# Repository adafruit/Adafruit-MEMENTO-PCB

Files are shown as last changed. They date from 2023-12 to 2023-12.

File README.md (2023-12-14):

## Adafruit MEMENTO - Python Programmable DIY Camera PCB

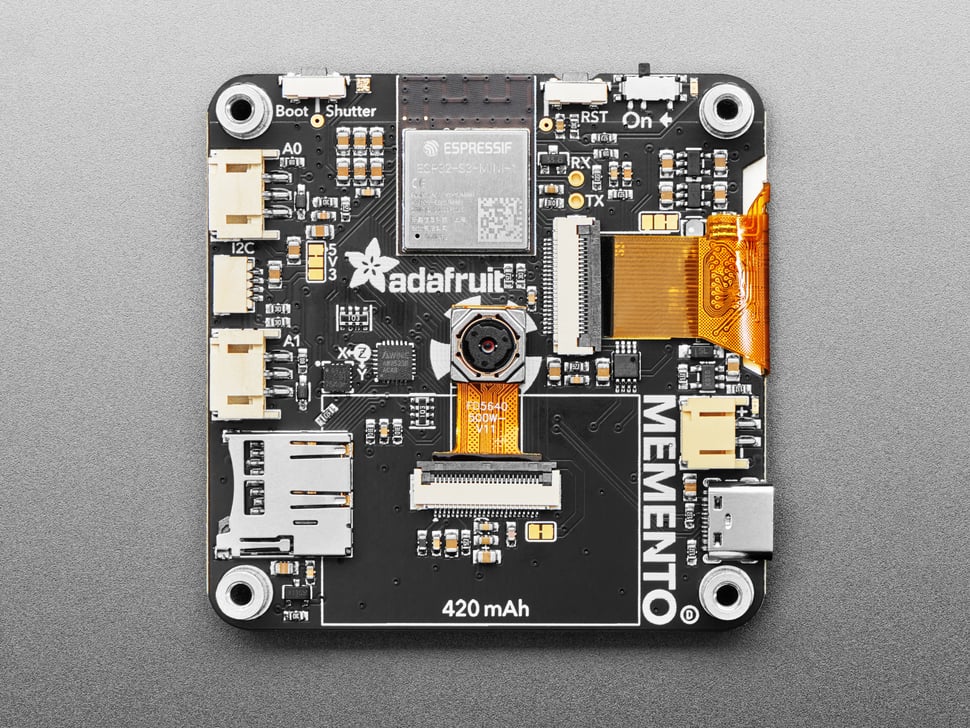
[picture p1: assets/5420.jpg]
<a href="http://www.adafruit.com/products/5420"><br/>
Click here to purchase one from the Adafruit shop</a>

PCB files for the Adafruit MEMENTO - Python Programmable DIY Camera. 

Format is EagleCAD schematic and board layout
* https://www.adafruit.com/product/5420

### Description

Make memories, or just a cool camera-based project, with Adafruit's MEMENTO Camera Board. It's a development board with everything you need to create programmable camera and vision projects: with a camera module, TFT preview screen, buttons, SD card slot and driven by a powerful ESP32-S3 with 2 MB of PSRAM for buffering 5 MegaPixel camera images.

This product is just the mainboard, and does not come with an enclosure, LED ring, hardware, SD card, or battery.

The ESP32-S3 is a WiFi and Bluetooth LE capable, 240 MHz dual core Tensilica processor - much like the famous ESP32. The S3 adds native USB support so it's great for use with Arduino or CircuitPython. The S3 also has the ability to interface with raw camera modules. The cameras require 12 GPIO pins and fast data transfer in order to get images off the sensor, and then a lot of memory for storing 2560 x 1920 images - which is why we picked an S3 module with 2MB of PSRAM so that we can read JPEGs into memory for saving onto an SD card.

To make the board easy to use we added a ton of supporting hardware, here's a full list of the hardware included:

* ESP32-S3 module with 8 MB Flash, 2 MB PSRAM - dual core 240MHz Tensilica with WiFi and BTLE.
* OV5640 camera module with 72 degree view and auto-focus motor - 5MP camera sensor with JPEG encoder built in.
* 1.54" 240x240 Color TFT - For previewing the camera images, or user interface design.
* MicroSD card slot - Store images or animations to any SPI-capable micro SD card.
* Two Digital/Analog Stemma Ports - JST PH-3 connectors for A0, A1 and power+ground for adding external buttons, LEDs, or sensors. Can provide 3V or 5V power.
* I2C Stemma QT Port - Connect just about any I2C sensor you please with a Stemma QT JST SH port, provides 3.3V power and logic.
* LIS3DH Accelerometer - Triple-access accelerometer can detect orientation, shaking or movement.
* LiPoly battery charging support - Use a 3.7/4.2V 350mA or 420mA battery for on-the-go snaps.
* 6 User Buttons - change modes, preview saved images, play DOOM (?). Connected through a GPIO expander
* Buzzer - play tones or alerts, or indicate when a photo was successfully taken
* Analog Microphone - Can be used as a sensor to detect loud sounds, not for recording video with audio.
* Shutter button - Connected to GPIO 0 for entering the ROM bootloader
* Reset button - For entering the bootloader or starting over
* On/Off switch - Cut all power when using a battery 
* USB Type C for programming the ESP32-S3, as well as REPL access in CircuitPython and charging the optional LiPoly battery
* Breakout pads for hardware UART - for more intense debugging needs, solder wires to the through-hole pads to connect to a console cable.
* Four M3 standoffs for mounting or enclosure attachment.

We've got both Arduino and CircuitPython example code that lets you preview the camera, adjust settings, and take photos that are saved to disk. However, we recommend CircuitPython because the compilation time in Arduino is pretty intense due to the huge amount of code required to run the camera. CircuitPython is fast to develop for and our library will make it easy to start making custom camera projects.

### License

Adafruit invests time and resources providing this open source design, please support Adafruit and open-source hardware by purchasing products from [Adafruit](https://www.adafruit.com)!

Designed by Limor Fried/Ladyada for Adafruit Industries.

Creative Commons Attribution/Share-Alike, all text above must be included in any redistribution. 
See license.txt for additional details.

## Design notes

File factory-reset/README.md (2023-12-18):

## Factory Reset file - MEMENTO - Python Programmable DIY Camera

This is the factory reset file for the MEMENTO - Python Programmable DIY Camera.

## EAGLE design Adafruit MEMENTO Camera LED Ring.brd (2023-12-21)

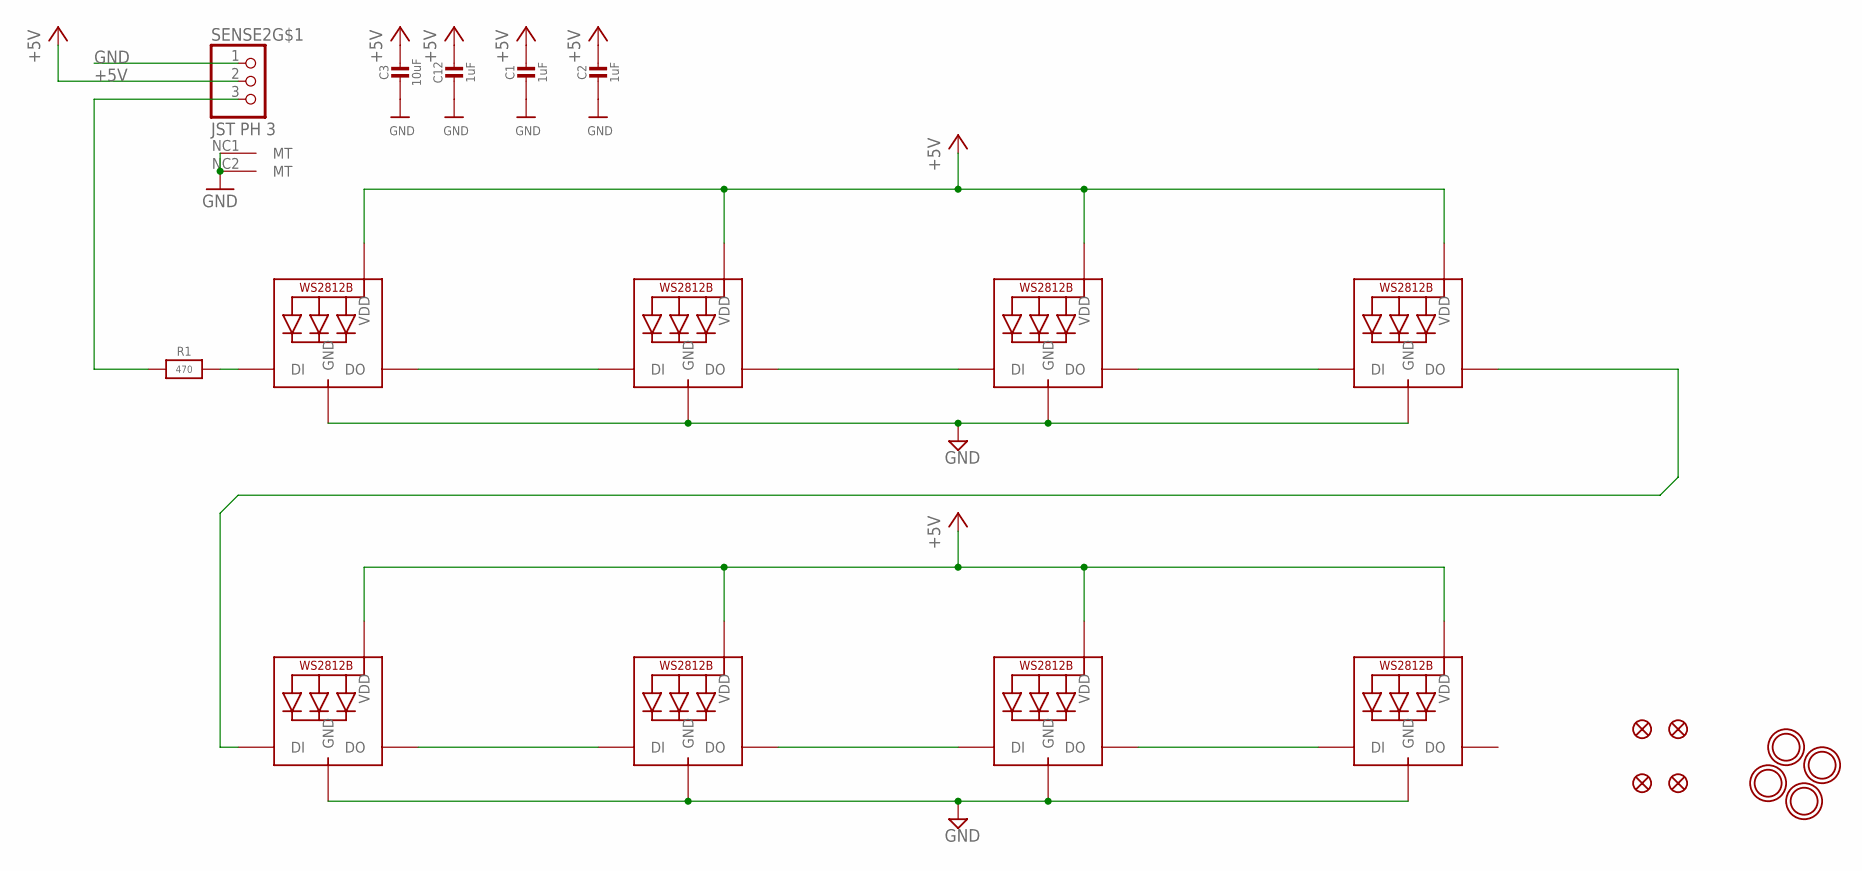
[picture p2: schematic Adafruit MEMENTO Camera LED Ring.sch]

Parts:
C1, C2, C12: 1uF; 0603-NO
C3: 10uF; 0805-NO
FID1, FID2, FID3, FID4: FIDUCIAL_1MM
LED1, LED3, LED5, LED7, LED9, LED11, LED13, LED15: WS2812B_5050N; WS2812B-NARROW
R1: 470; 0603-NO
SENSE2: JST PH 3; JSTPH3
U$1, U$2, U$3, U$4: MOUNTINGHOLE3.0THIN; MOUNTINGHOLE_3.0_PLATEDTHIN

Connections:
+5V: C1.1, C2.1, C3.1, C12.1, LED1.1-VDD (VDD), LED3.1-VDD (VDD), LED5.1-VDD (VDD), LED7.1-VDD (VDD), LED9.1-VDD (VDD), LED11.1-VDD (VDD), LED13.1-VDD (VDD), LED15.1-VDD (VDD), SENSE2.2
GND: C1.2, C2.2, C3.2, C12.2, LED1.3-GND (GND), LED3.3-GND (GND), LED5.3-GND (GND), LED7.3-GND (GND), LED9.3-GND (GND), LED11.3-GND (GND), LED13.3-GND (GND), LED15.3-GND (GND), SENSE2.1, SENSE2.NC1 (MT), SENSE2.NC2 (MT)
IN: R1.1, SENSE2.3
unnamed: LED1.2-DOUT (DO), LED3.4-DIN (DI)
unnamed: LED3.2-DOUT (DO), LED5.4-DIN (DI)
unnamed: LED5.2-DOUT (DO), LED7.4-DIN (DI)
unnamed: LED9.2-DOUT (DO), LED11.4-DIN (DI)
unnamed: LED11.2-DOUT (DO), LED13.4-DIN (DI)
unnamed: LED13.2-DOUT (DO), LED15.4-DIN (DI)
unnamed: LED7.2-DOUT (DO), LED9.4-DIN (DI)
unnamed: LED1.4-DIN (DI), R1.2

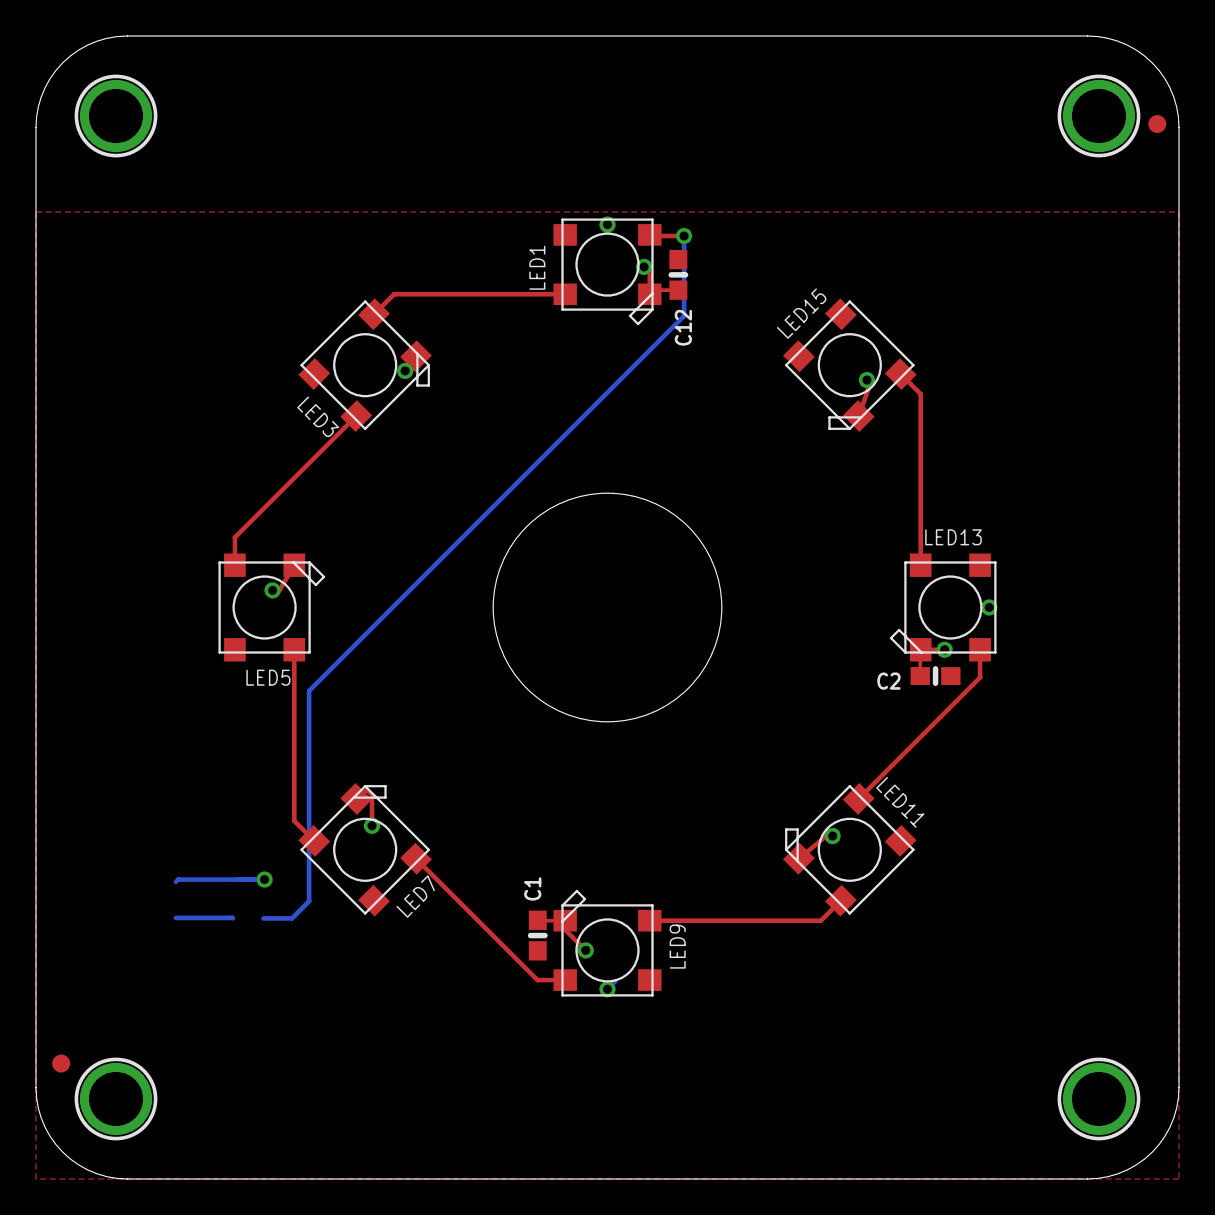
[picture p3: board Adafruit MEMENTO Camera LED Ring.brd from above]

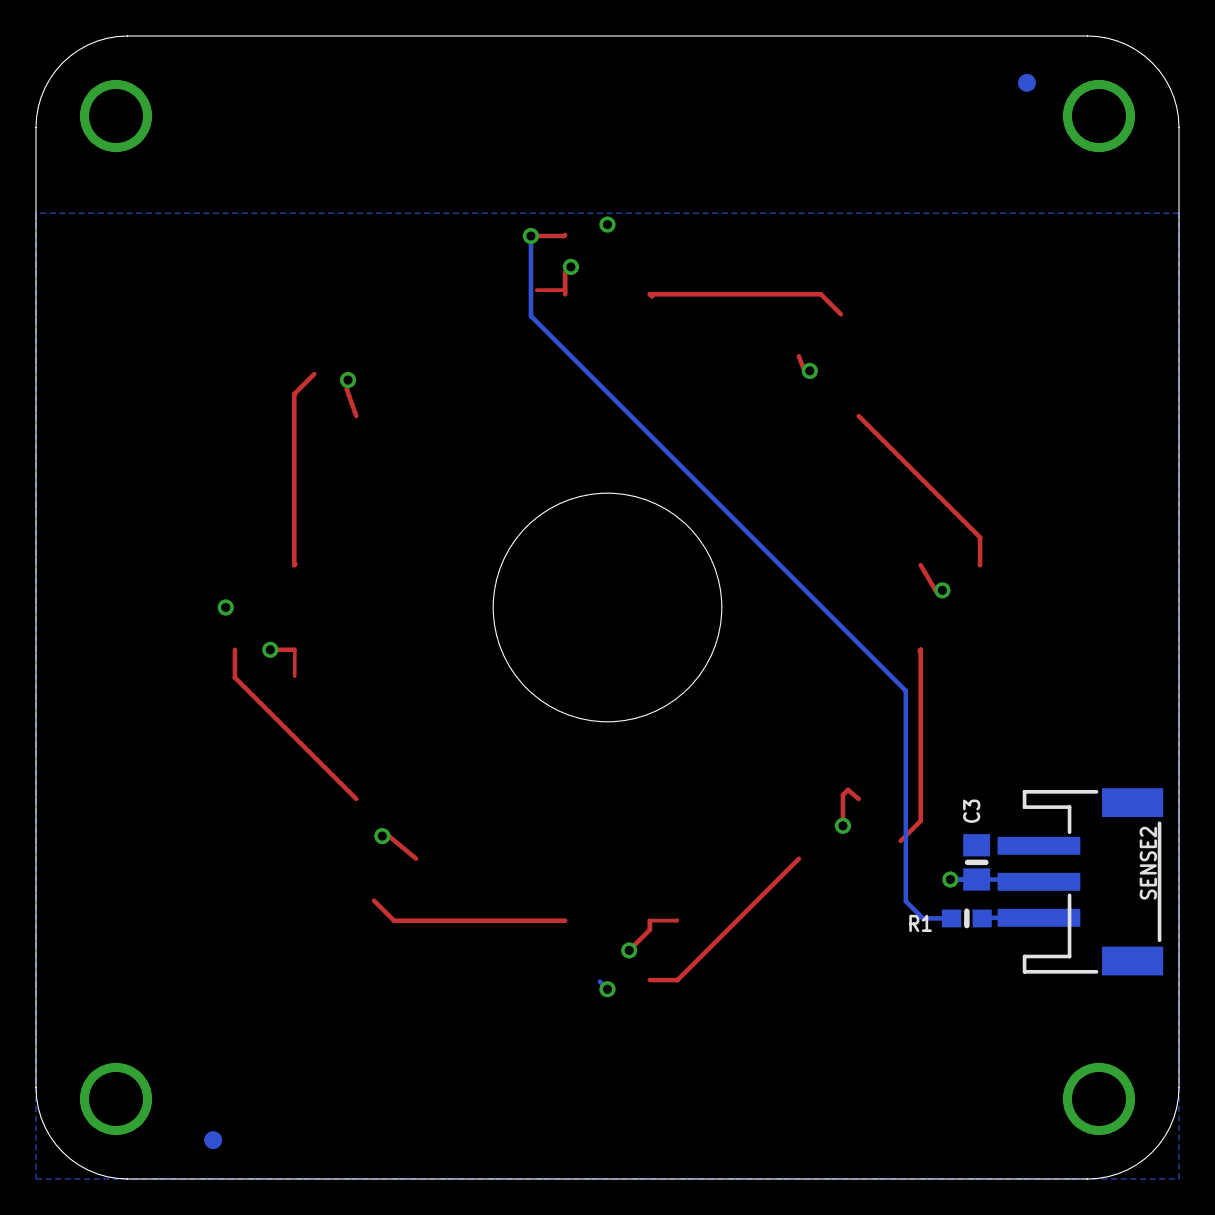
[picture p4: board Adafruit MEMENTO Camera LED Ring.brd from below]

Board: 2 copper layers, 63.5 x 63.5 mm, 24 parts (6 on the bottom side), 11 nets.

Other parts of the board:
U$8: MEMENTO_LED_BOT
U$9: MEMENTO_LED_TOP

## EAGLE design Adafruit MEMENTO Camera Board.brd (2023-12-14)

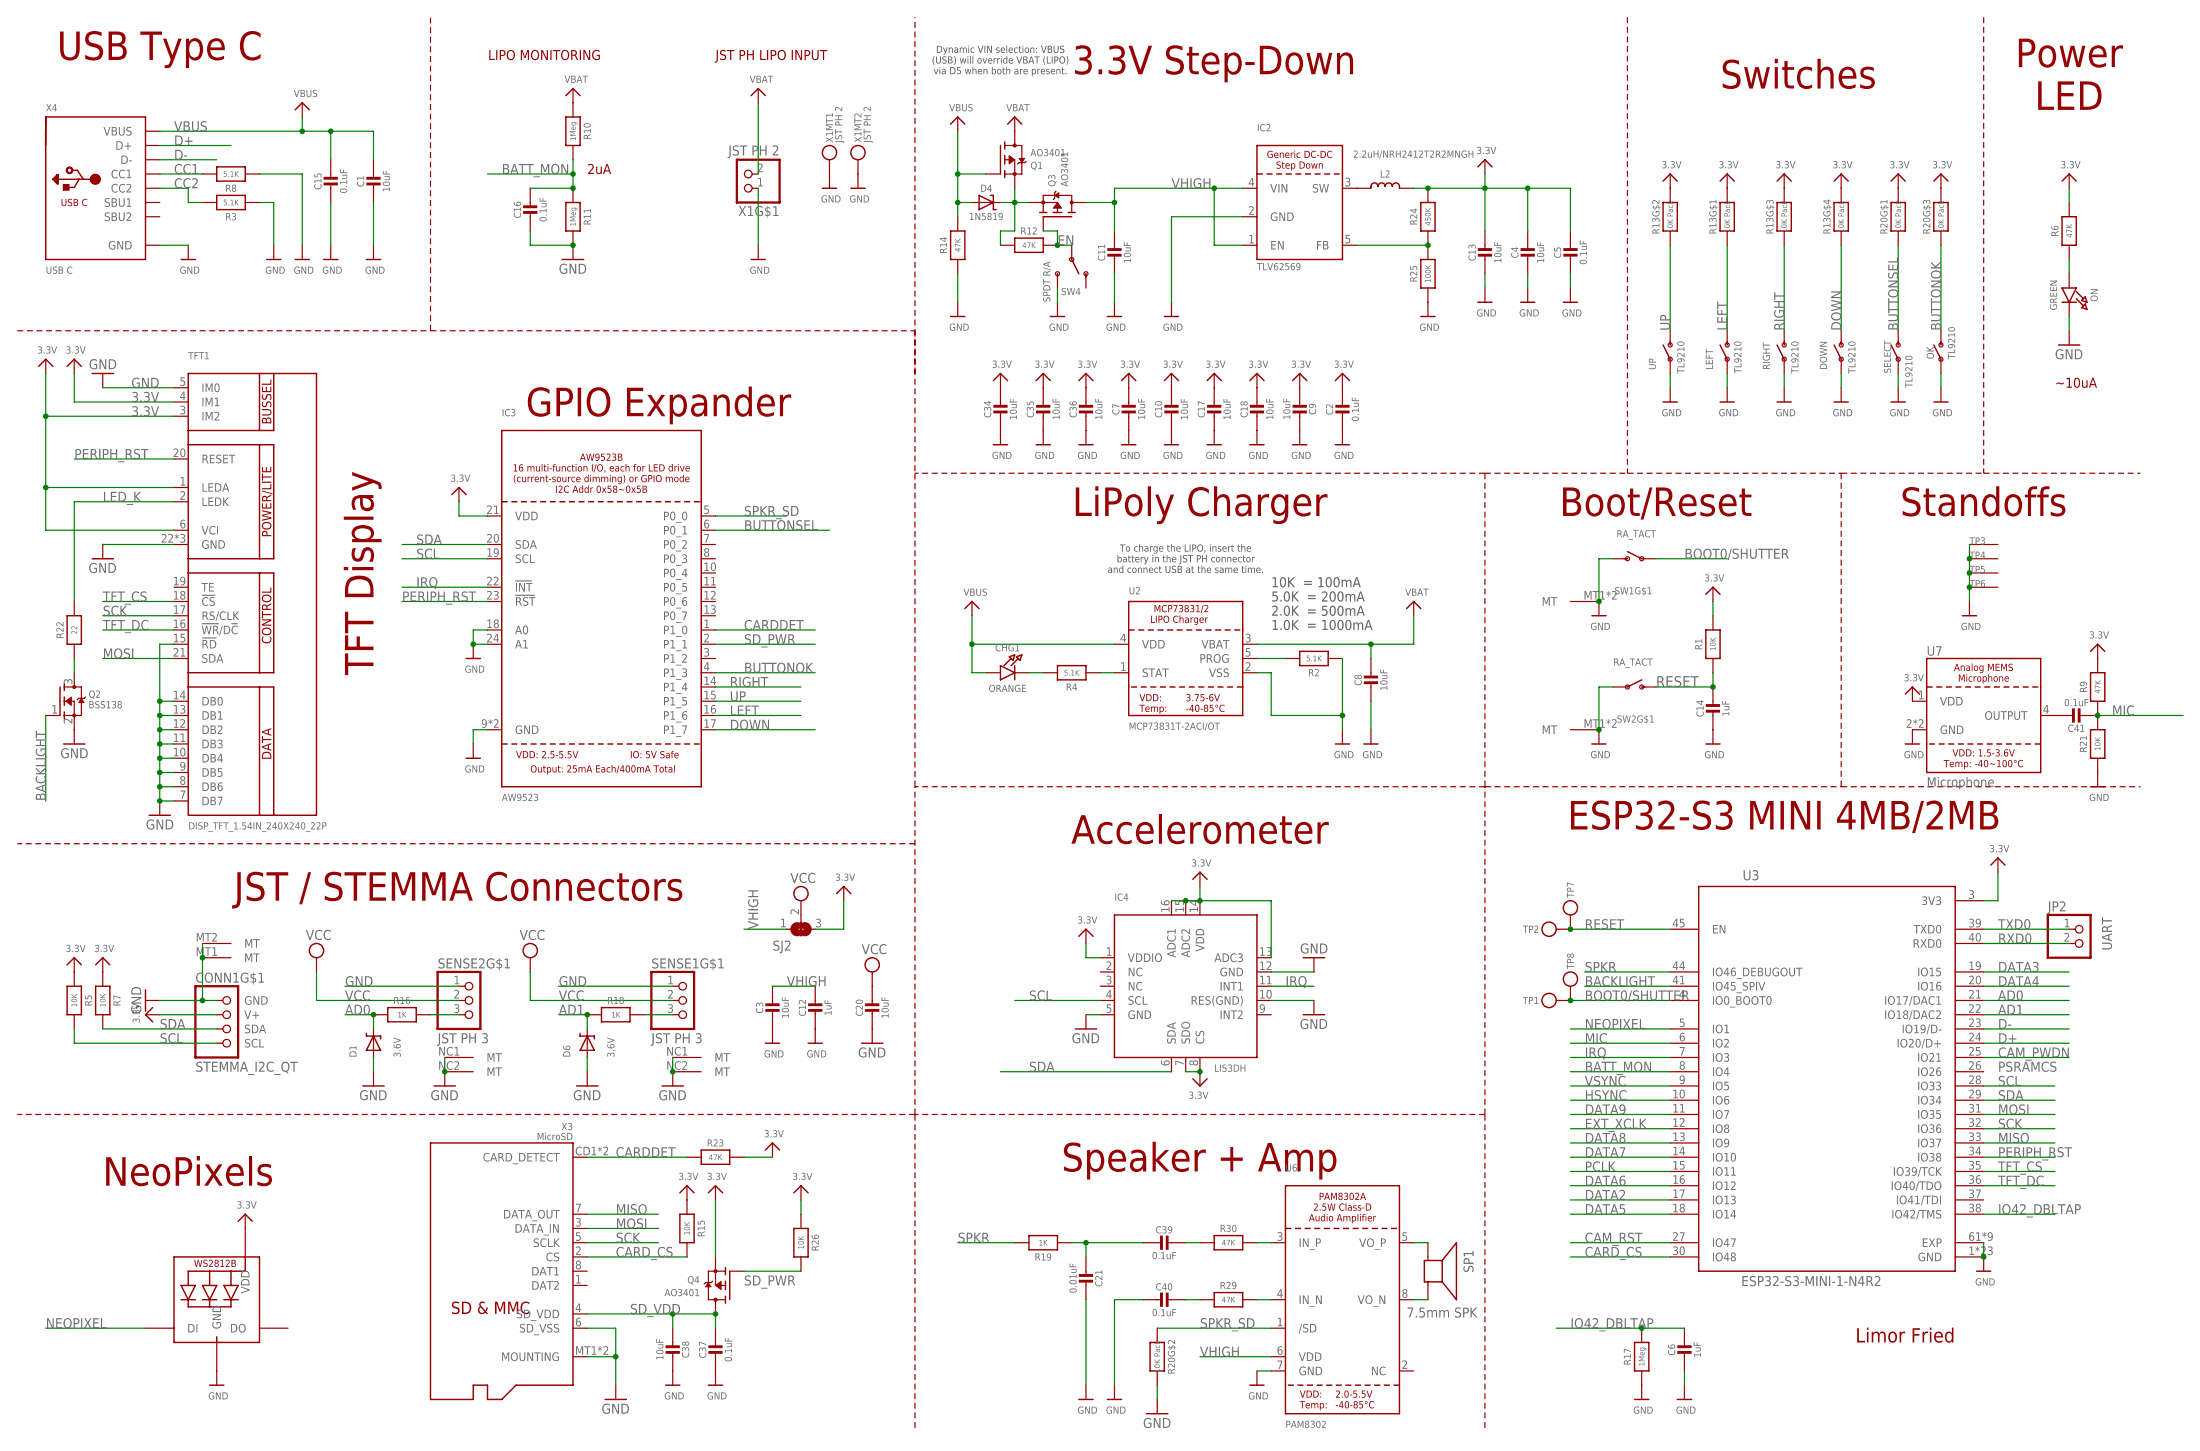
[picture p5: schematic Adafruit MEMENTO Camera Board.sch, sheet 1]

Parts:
C1, C3, C4, C7, C8, C9, C10, C11, C13, C17, C18, C20, C34, C35, C36, C38: 10uF; 0805-NO
C2, C5, C15, C16, C37, C39, C40, C41: 0.1uF; 0603-NO
C6, C12, C14: 1uF; 0603-NO
C21: 0.01uF; 0603-NO
CHG1: ORANGE; CHIPLED_0603_NOOUTLINE
CONN1: STEMMA_I2C_QT; JST_SH4
D1, D6: 3.6V; SOD-323
D4: 1N5819; SOD-123
DOWN: TL9210
IC2: TLV62569; SOT23-5
IC3: AW9523; QFN24_4MM_SMSC
IC4: LIS3DH; LGA16_3X3MM
JP2: UART; 1X02_ROUND
L2: 2.2uH/NRH2412T2R2MNGH; INDUCTOR_TAIYOYUDEN_NR3015
LED2: WS2812B_SK6805_1515; SK6805_1515
LEFT: TL9210
OK: TL9210
ON: GREEN; CHIPLED_0603_NOOUTLINE
Q1, Q3, Q4: AO3401; SOT23-R
Q2: BSS138; SOT23-WIDE
R1, R5, R7, R15, R21, R26: 10K; 0603-NO
R2, R3, R4, R8: 5.1K; 0603-NO
R6, R9, R12, R14, R23, R29, R30: 47K; 0603-NO
R10, R11, R17: 1Meg; 0603-NO
R13, R20: 10K Pack; RESPACK_4X0603
R16, R18, R19: 1K; 0603-NO
R22: 22; 0603-NO
R24: 450K; 0603-NO
R25: 100K; 0603-NO
RIGHT: TL9210
SELECT: TL9210
SENSE1, SENSE2: JST PH 3; JSTPH3
SJ2: SOLDERJUMPER_2WAY; SOLDERJUMPER_2WAY_OPEN_NOPASTE
SP1: 7.5mm SPK; BUZZER_SMT_7.5MM
SW1, SW2: RA_TACT; SPST_TACTILE_RA
SW4: SPDT R/A; SPDT_SMT_SSSS811101
TFT1: DISP_TFT_1.54IN_240X240_22P; TFT_1.54IN_240X240_22PIN
TP1, TP2, TP7, TP8: TESTPOINTROUND1.5MMNO; TESTPOINT_ROUND_1.5MM_NO
TP3, TP4, TP5, TP6: SEWTAP_SMTNUTM3; SMT_NUT_3MM
U2: MCP73831T-2ACI/OT; SOT23-5
U3: ESP32-S3-MINI-1-N4R2; ESP32-S2-MINI-1
U6: PAM8302; MSOP8_0.65MM
U7: Microphone; MEMS_MIC_2.75X1.85
UP: TL9210
X1: JST PH 2; JSTPH2_BATT
X3: MicroSD; MICROSD
X4: USB C; USB_C_CUSB31-CFM2AX-01-X

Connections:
3.3V: C2.1, C4.1, C5.1, C7.1, C9.2, C10.1, C13.1, C17.1, C18.1, C34.1, C35.1, C36.1, CONN1.2 (V+), IC3.21 (VDD), IC4.1 (VDDIO), IC4.7 (SDO), IC4.8 (CS), IC4.13 (ADC3), IC4.14 (VDD), IC4.15 (ADC2), IC4.16 (ADC1), L2.P$2 (2), LED2.2 (VDD), Q4.2 (S), R1.2, R5.1, R6.2, R7.1, R9.2, R13.5 (2), R13.6 (2), R13.7 (2), R13.8 (2), R15.2, R20.6 (2), R20.8 (2), R23.2, R24.2, R26.1, SJ2.3, TFT1.1 (LEDA), TFT1.3 (IM2), TFT1.4 (IM1), TFT1.6 (VCI), U3.3 (3V3), U7.1 (VDD); also elsewhere on the board
A1_JST1: R18.1, SENSE1.3
AD0: D1.C, R16.2, U3.21 (IO17/DAC1)
AD1: D6.C, R18.2, U3.22 (IO18/DAC2)
BACKLIGHT: Q2.1 (G), U3.41 (IO45_SPIV)
BATT_MON: C16.1, R10.2, R11.1, U3.8 (IO4)
BOOT0/SHUTTER: SW1.1, TP1.P$1, TP8.P$1, U3.4 (IO0_BOOT0)
BUTTONOK: IC3.4 (P1_3), OK.2 (S), R20.3 (1)
BUTTONSEL: IC3.6 (P0_1), R20.1, SELECT.2 (S)
CAM_PWDN: U3.25 (IO21); also elsewhere on the board
CAM_RST: U3.27 (IO47); also elsewhere on the board
CARDDET: IC3.1 (P1_0), R23.1, X3.CD1 (CARD_DETECT), X3.CD2 (CARD_DETECT)
CARD_CS: R15.1, U3.30 (IO48), X3.2 (CS)
CC1: R8.2, X4.A5 (CC1)
CC2: R3.2, X4.B5 (CC2)
D10_JST: R16.1, SENSE2.3
D+: U3.24 (IO20/D+), X4.A6 (D+), X4.B6 (D+)
D-: U3.23 (IO19/D-), X4.A7 (D-), X4.B7 (D-)
DATA2: U3.17 (IO13); also elsewhere on the board
DATA3: U3.19 (IO15); also elsewhere on the board
DATA4: U3.20 (IO16); also elsewhere on the board
DATA5: U3.18 (IO14); also elsewhere on the board
DATA6: U3.16 (IO12); also elsewhere on the board
DATA7: U3.14 (IO10); also elsewhere on the board
DATA8: U3.13 (IO9); also elsewhere on the board
DATA9: U3.11 (IO7); also elsewhere on the board
DOWN: DOWN.2 (S), IC3.17 (P1_7), R13.4 (1)
EN: Q3.1 (G), R12.2, SW4.B
EXT_XCLK: U3.12 (IO8); also elsewhere on the board
FB: IC2.5 (FB), R24.1, R25.2
GND: C1.2, C2.2, C3.2, C4.2, C5.2, C6.2, C7.2, C8.2, C9.1, C10.2, C11.2, C12.2, C13.2, C14.2, C15.2, C16.2, C17.2, C18.2, C20.2, C21.1, C34.2, C35.2, C36.2, C37.2, C38.1, C40.2, CONN1.1 (GND), CONN1.MT1 (MT), CONN1.MT2 (MT), D1.A, D6.A, DOWN.1, IC2.2 (GND), IC3.9 (GND), IC3.18 (A0), IC3.24 (A1), IC3.THERM (GND), IC4.5 (GND), IC4.10 (RES(GND)), IC4.12 (GND), LED2.4 (GND), LEFT.1, OK.1, ON.C, Q2.2 (S), R2.1, R3.1, R8.1, R11.2, R14.1, R17.1, R20.7 (2), R21.1, R25.1, RIGHT.1, SELECT.1, SENSE1.1, SENSE1.NC1 (MT), SENSE1.NC2 (MT), SENSE2.1, SENSE2.NC1 (MT), SENSE2.NC2 (MT), SW1.2 (S), SW1.MT1 (MT), SW1.MT2 (MT), SW2.1, SW2.MT1 (MT), SW2.MT2 (MT), SW4.C (S), TFT1.5 (IM0), TFT1.7 (DB7), TFT1.8 (DB6), TFT1.9 (DB5), TFT1.10 (DB4), TFT1.11 (DB3), TFT1.12 (DB2), TFT1.13 (DB1), TFT1.14 (DB0), TFT1.15 (!RD), TFT1.22 (GND), TFT1.SUPPORT1 (GND), TFT1.SUPPORT2 (GND), TP3.P$1, TP4.P$1, TP5.P$1, TP6.P$1, U2.2 (VSS), U3.1 (GND), U3.2 (GND), U3.42 (GND), U3.43 (GND), U3.46 (GND), U3.47 (GND), U3.48 (GND), U3.49 (GND), U3.50 (GND), U3.51 (GND), U3.52 (GND), U3.53 (GND), U3.54 (GND), U3.55 (GND), U3.56 (GND), U3.57 (GND), U3.58 (GND), U3.59 (GND), U3.60 (GND), U3.61 (EXP), U3.62 (GND), U3.63 (GND), U3.64 (GND), U3.65 (GND), U3.66 (EXP), U3.67 (EXP), U3.68 (EXP), U3.69 (EXP), U3.70 (EXP), U3.71 (EXP), U3.72 (EXP), U3.73 (EXP), U6.7 (GND), U7.2 (GND), U7.3 (GND), UP.1, X1.1, X1.NC1, X1.NC2, X3.6 (SD_VSS), X3.MT1 (MOUNTING), X3.MT2 (MOUNTING), X4.A1B12 (GND), X4.B1A12 (GND); also elsewhere on the board
HSYNC: U3.10 (IO6); also elsewhere on the board
IO42_DBLTAP: C6.1, R17.2, U3.38 (IO42/TMS)
IRQ: IC3.22 (!INT), IC4.11 (INT1), U3.7 (IO3)
LED_K: R22.1, TFT1.2 (LEDK)
LEFT: IC3.16 (P1_6), LEFT.2 (S), R13.1
MIC: C41.2, R9.1, R21.2, U3.6 (IO2)
MISO: U3.33 (IO37), X3.7 (DATA_OUT)
MOSI: TFT1.21 (SDA), U3.31 (IO35), X3.3 (DATA_IN)
unnamed: C41.1, U7.4 (OUTPUT)
unnamed: ON.A, R6.1
unnamed: R4.1, U2.1 (STAT)
unnamed: Q2.3 (D), R22.2
unnamed: CHG1.C, R4.2
unnamed: R29.2, U6.4 (IN_N)
unnamed: R30.2, U6.3 (IN_P)
unnamed: R2.2, U2.5 (PROG)
unnamed: C40.1, R29.1
unnamed: SP1.-, U6.8 (VO_N)
unnamed: SP1.+, U6.5 (VO_P)
unnamed: C39.1, R30.1
unnamed: C21.2, C39.2, R19.1
unnamed: IC2.3 (SW), L2.P$1 (1)
unnamed: D4.C, Q1.2 (S), Q3.2 (S), R12.1
NEOPIXEL: LED2.1 (DI), U3.5 (IO1)
PCLK: U3.15 (IO11); also elsewhere on the board
PERIPH_RST: IC3.23 (!RST), TFT1.20 (RESET), U3.34 (IO38)
RESET: C14.1, R1.1, SW2.2 (S), TP2.P$1, TP7.P$1, U3.45 (EN)
RIGHT: IC3.14 (P1_4), R13.3 (1), RIGHT.2 (S)
RXD0: JP2.2, U3.40 (RXD0)
SCK: TFT1.17 (RS/CLK), U3.32 (IO36), X3.5 (SCLK)
SCL: CONN1.4 (SCL), IC3.19 (SCL), IC4.4 (SCL), R5.2, U3.28 (IO33); also elsewhere on the board
SDA: CONN1.3 (SDA), IC3.20 (SDA), IC4.6 (SDA), R7.2, U3.29 (IO34); also elsewhere on the board
SD_PWR: IC3.2 (P1_1), Q4.1 (G), R26.2
SD_VDD: C37.1, C38.2, Q4.3 (D), X3.4 (SD_VDD)
SPKR: R19.2, U3.44 (IO46_DEBUGOUT)
SPKR_SD: IC3.5 (P0_0), R20.2 (1), U6.1 (/SD)
TFT_CS: TFT1.18 (!CS), U3.35 (IO39/TCK)
TFT_DC: TFT1.16 (!WR!/D!C), U3.36 (IO40/TDO)
TXD0: JP2.1, U3.39 (TXD0)
UP: IC3.15 (P1_5), R13.2 (1), UP.2 (S)
VBAT: C8.1, Q1.3 (D), R10.1, U2.3 (VBAT), X1.2
VBUS: C1.1, C15.1, CHG1.A, D4.A, Q1.1 (G), R14.2, U2.4 (VDD), X4.A4B9 (VBUS), X4.B4A9 (VBUS)
VCC: C20.1, SENSE1.2, SENSE2.2, SJ2.2
VHIGH: C3.1, C11.1, C12.1, IC2.1 (EN), IC2.4 (VIN), Q3.3 (D), SJ2.1, U6.6 (VDD); also elsewhere on the board
VSYNC: U3.9 (IO5); also elsewhere on the board

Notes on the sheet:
Limor Fried
10K = 100mA
5.0K = 200mA
2.0K = 500mA
1.0K = 1000mA
LIPO MONITORING
To charge the LIPO, insert the battery in the JST PH connector and connect USB at the same time.
JST PH LIPO INPUT
Dynamic VIN selection: VBUS (USB) will override VBAT (LIPO) via D5 when both are present.
PSRAMCS
2uA
~10uA
TFT Display
LiPoly Charger
Accelerometer
Speaker + Amp
3.3V Step-Down
ESP32-S3 MINI 4MB/2MB
Switches
Boot/Reset
USB Type C
Power LED
NeoPixels
JST / STEMMA Connectors
Standoffs
GPIO Expander

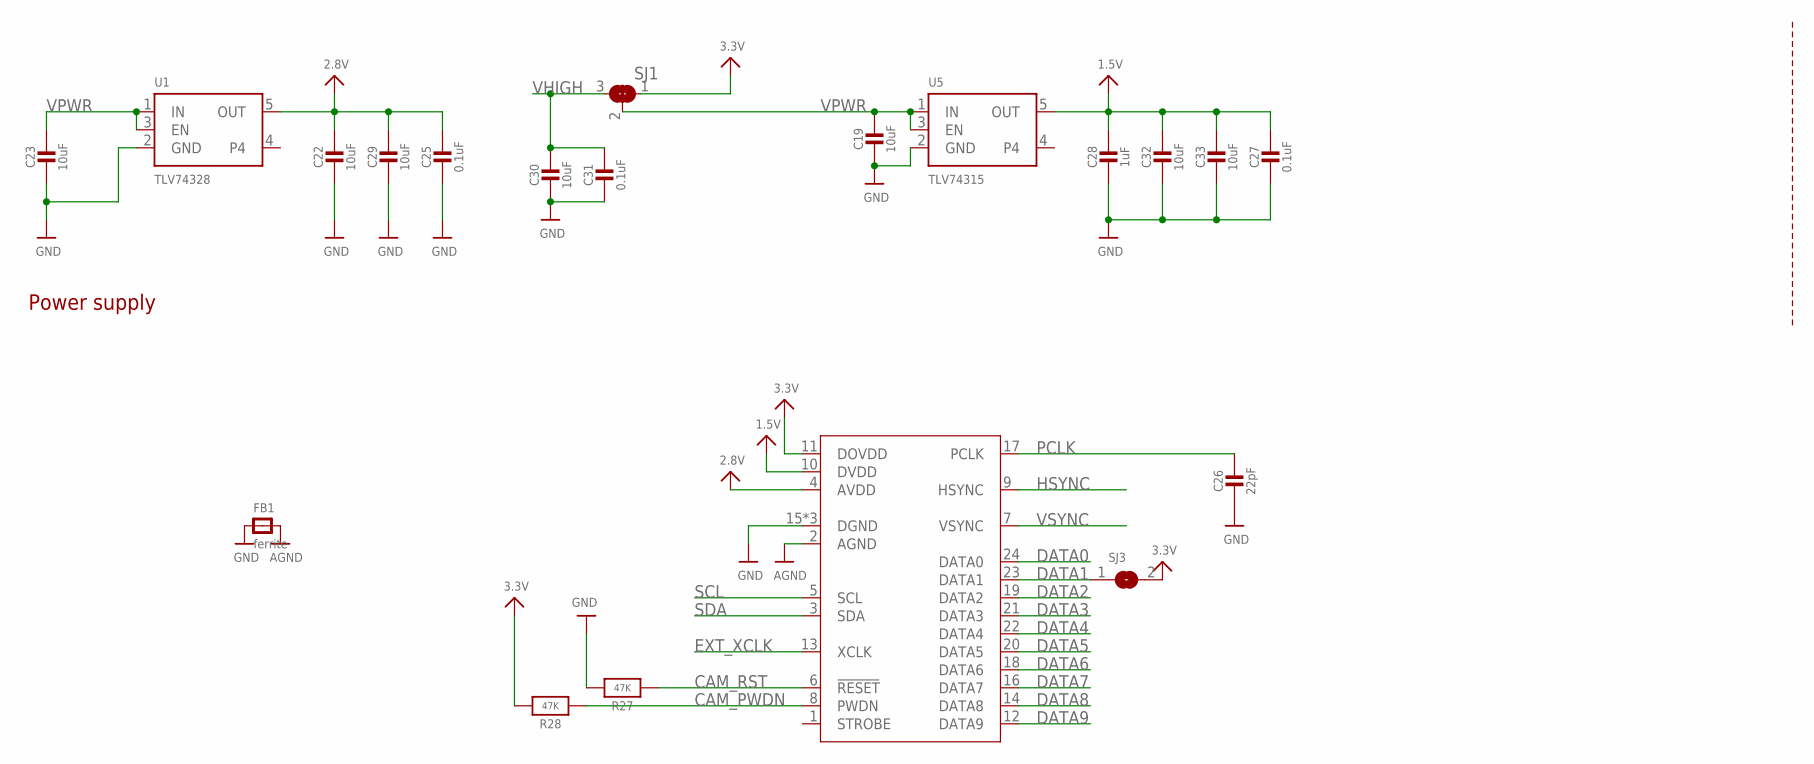
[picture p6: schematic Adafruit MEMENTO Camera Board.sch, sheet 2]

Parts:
C19, C22, C23, C29, C30, C32, C33: 10uF; 0805-NO
C25, C27, C31: 0.1uF; 0603-NO
C26: 22pF; 0603-NO
C28: 1uF; 0603-NO
FB1: ferrite; 0603-NO
R27, R28: 47K; 0603-NO
SJ1: SOLDERJUMPER_2WAY; SOLDERJUMPER_2WAY_OPEN_NOPASTE
SJ3: SOLDERJUMPERCLOSED; SOLDERJUMPER_CLOSEDWIRE
U1: TLV74328; SOT23-5; JLC_ROTATION 0
U5: TLV74315; SOT23-5; JLC_ROTATION 0
X2: CAMERA_OV2640; OV2640FSL

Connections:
1.5V: C27.1, C28.1, C32.1, C33.1, U5.5 (OUT), X2.10 (DVDD)
2.8V: C22.1, C25.1, C29.1, U1.5 (OUT), X2.4 (AVDD)
3.3V: R28.2, SJ1.1, SJ3.2, X2.11 (DOVDD); also elsewhere on the board
AGND: FB1.2, X2.2 (AGND)
CAM_PWDN: R28.1, X2.8 (PWDN); also elsewhere on the board
CAM_RST: R27.1, X2.6 (!RESET); also elsewhere on the board
DATA0: X2.24 (DATA0)
DATA1: SJ3.1, X2.23 (DATA1)
DATA2: X2.19 (DATA2); also elsewhere on the board
DATA3: X2.21 (DATA3); also elsewhere on the board
DATA4: X2.22 (DATA4); also elsewhere on the board
DATA5: X2.20 (DATA5); also elsewhere on the board
DATA6: X2.18 (DATA6); also elsewhere on the board
DATA7: X2.16 (DATA7); also elsewhere on the board
DATA8: X2.14 (DATA8); also elsewhere on the board
DATA9: X2.12 (DATA9); also elsewhere on the board
EXT_XCLK: X2.13 (XCLK); also elsewhere on the board
GND: C19.2, C22.2, C23.2, C25.2, C26.2, C27.2, C28.2, C29.2, C30.2, C31.2, C32.2, C33.2, FB1.1, R27.2, U1.2 (GND), U5.2 (GND), X2.15 (DGND), X2.SPRT1 (DGND), X2.SPRT2 (DGND); also elsewhere on the board
HSYNC: X2.9 (HSYNC); also elsewhere on the board
PCLK: C26.1, X2.17 (PCLK); also elsewhere on the board
SCL: X2.5 (SCL); also elsewhere on the board
SDA: X2.3 (SDA); also elsewhere on the board
VHIGH: C30.1, C31.1, SJ1.3; also elsewhere on the board
VPWR: C19.1, C23.1, SJ1.2, U1.1 (IN), U1.3 (EN), U5.1 (IN), U5.3 (EN)
VSYNC: X2.7 (VSYNC); also elsewhere on the board

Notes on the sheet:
Power supply

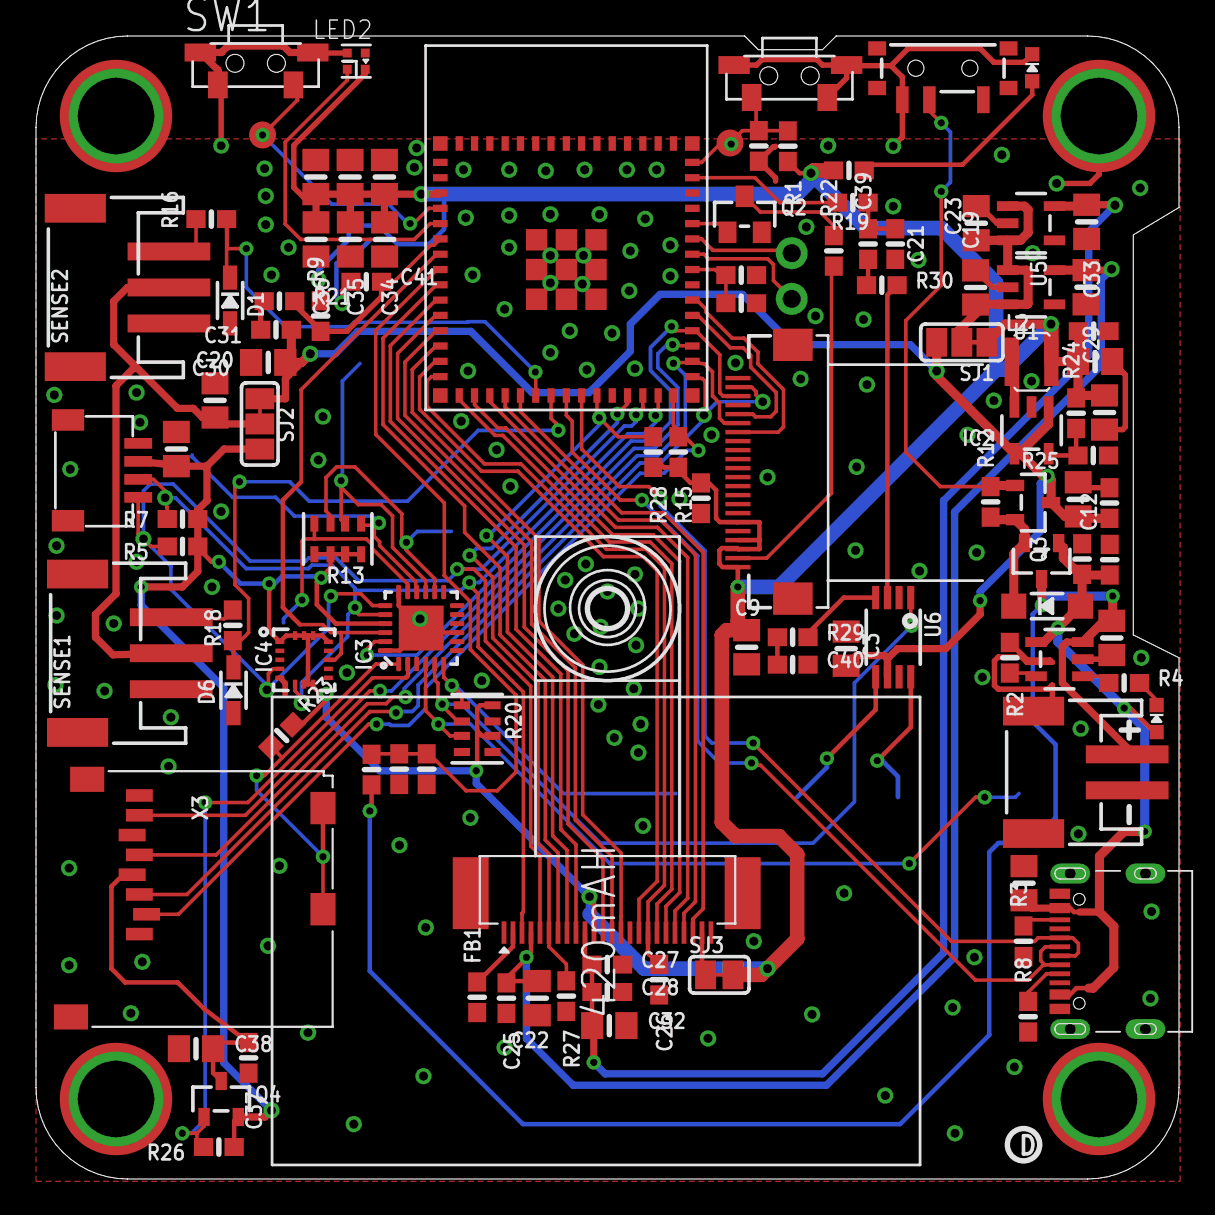
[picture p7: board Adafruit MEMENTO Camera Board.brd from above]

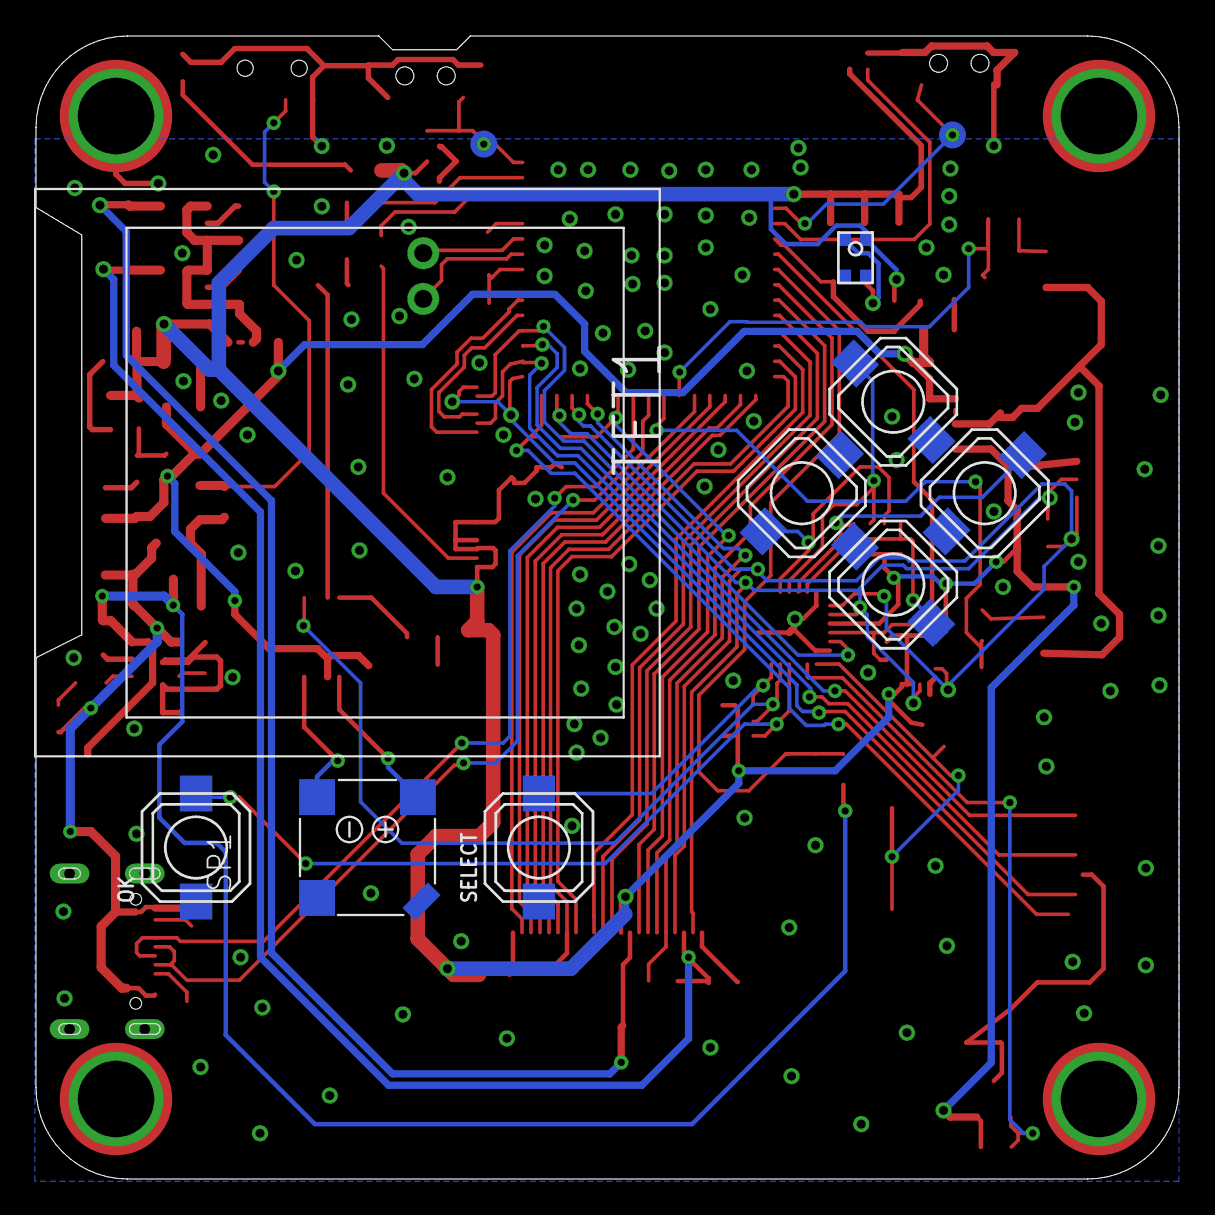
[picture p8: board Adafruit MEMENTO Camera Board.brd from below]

Board: 2 copper layers, 63.5 x 63.5 mm, 125 parts (12 on the bottom side), 81 nets.

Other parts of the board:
U$83: LIPO_552535
U$119: MEMENTO_TOP
U$120: MEMENTO_BOT
U$121: PCBFEAT-REV-040

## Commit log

2023-12-14 adding cookiecutter output
    [Adafruit MEMENTO Camera Board.brd, Adafruit MEMENTO Camera Board.sch]
2023-12-21 adding led ring and backplate
    [Adafruit MEMENTO Backplate.brd, Adafruit MEMENTO Backplate.sch, Adafruit MEMENTO Camera LED Ring.brd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]

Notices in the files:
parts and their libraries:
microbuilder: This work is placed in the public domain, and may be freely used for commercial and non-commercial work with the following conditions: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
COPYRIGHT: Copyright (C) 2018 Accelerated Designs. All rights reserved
